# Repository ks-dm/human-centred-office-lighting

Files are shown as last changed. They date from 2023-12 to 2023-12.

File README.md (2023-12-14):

# human-centred-office-lighting
 
 This project pilots an ergonomic lighting system that mimics natural daylight, complementing the human environment, created for my 4th year Internet of Things elective module.

 This repository contains relevant code, tools and files to recereate the tests outline in the [report](doc/Human_centred_office_lighting.pdf), found under doc.
 
## Video
<a href="https://www.youtube.com/watch?v=UIQVlB2CDCI">
    
</a>

# CAD
Ive included relevant STEP files and parts lists in case you want to build the skylights and interface detailed in the [report](doc/Human_centred_office_lighting.pdf)

## Skylights
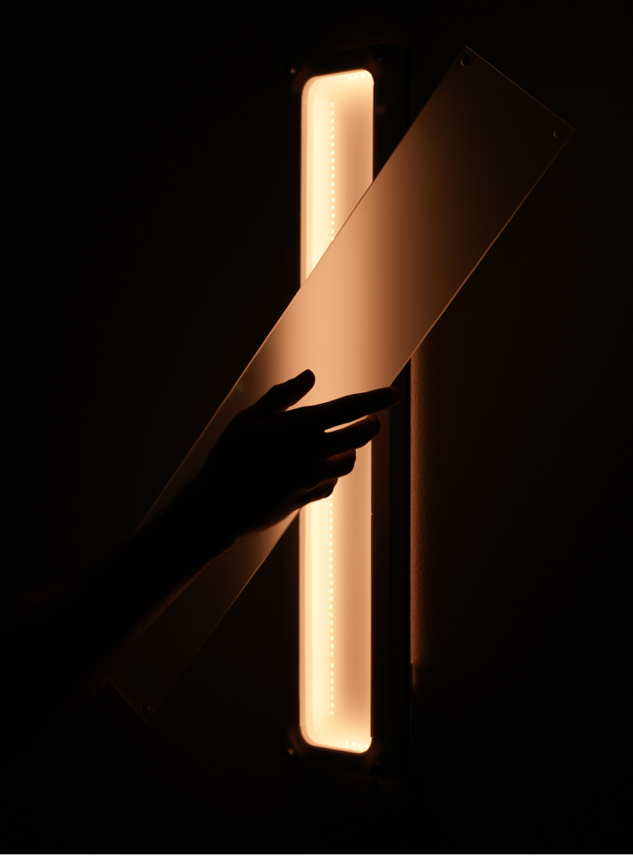
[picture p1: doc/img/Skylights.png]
Skylight


The skylights can be made using only a laser cutter, and I've included the .dxf files for each sheet material in this repo. Adjust the power and speed according to you machine specs.

The enclosures are made from the following materials:
 - [144/m WS2812B RGB LED strip](https://www.amazon.co.uk/dp/B07Q9KCC6M?psc=1&ref=ppx_yo2ov_dt_b_product_details), these are unrbanded neopixels, and I was able to fit around 174 of them in each Skylight. That equated to around 4 Metres to make 3 Skylights. You'll have to cut these into two long strips of 75 LEDs and two short strips of 12 LEDs per light, and solder them back into a continuous loop.
 - [9mm birch plywood](https://www.techsoft.co.uk/products/laser-cutting-materials/laser-grade-plywood-birch), The inner volume of the skylight is created with 3 layers of this 9mm laser ply, connected with wood glue. The DXF file included splits each layer into 4 parts for better tesselation and material use. You could also route this part out of a thicker stock of MDF or plywood if you have access to a CNC.
 - [3mm White Acrylic](https://www.techsoft.co.uk/products/laser-cutting-materials/acrylic-coloured-clear), this amkes up the tob and bottom of the plywood sandwhich. The LED strips also get attached to the top piece of acrylic. Refer to the video to see how this is done.
 - [3mm Frosted Perspex](https://www.cutmy.co.uk/plastic/acrylic-perspex-sheets/frosted/), I reccomend getting a large stock of this and lasercutting.
 - [12mm standoffs](https://www.amazon.co.uk/dp/B0851MNP1F?psc=1&ref=ppx_yo2ov_dt_b_product_details) Any generic standoff will work, but the brushed steel ones used for mirrors help create a nice touch!

## Ambient interface
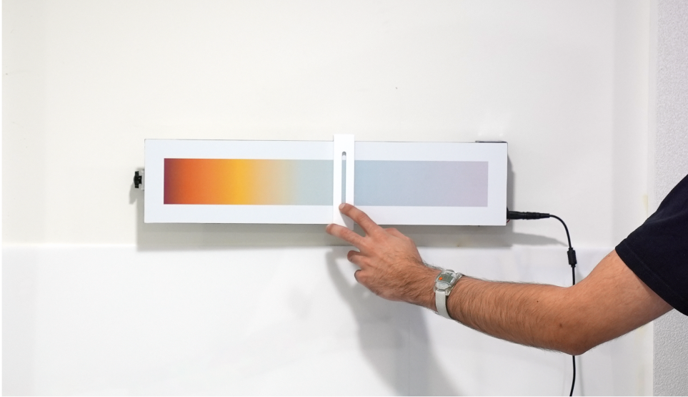
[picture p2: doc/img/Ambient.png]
Interface


The ambient interface uses a variety of readily available 3D printer parts, a custom dibond panel and a few 3D printed sections. I've linked below UK based distributors, but you should be able to find these parts locally pretty easily.

Components:
 - [2040 V-Slot Aluminium Profile](https://printermods.co.uk/products/sku11014?variant=39904045334678) cut to 450mm
 - [3D printer Belt Tensioner](https://printermods.co.uk/products/sku12534?variant=43025082056950) you can probably get away with 3D printing one of these and adding a GT2 20T timing belt pulley yourself
 - [M4 T-Nuts](https://printermods.co.uk/products/sku11148?variant=36960296272022) used to attach everything to the 2040 profile, including wall mounts
 - [Pulley wheels w/ bearing](https://printermods.co.uk/products/sku10855?variant=36915990429846) Attached these to the printed gantry with M5 nuts / bolts
 - [GT2-6mm Timing Belt](https://printermods.co.uk/products/sku12225?variant=39977974562966)
 - [TMC2130 Stepper motor driver](https://printermods.co.uk/products/sku10554?variant=37188251451542) Feel free to substitute - this operates nice and silently on 12-24V
 - [Endstop limit switch](https://printermods.co.uk/products/sku11838?variant=37518415102102) CAD is dimensioned to fit this PCB, however it seems to be a common form factor of this switch
 - [Raspberry Pi Zero](https://shop.pimoroni.com/products/raspberry-pi-zero-2-w?variant=39493046075475) You'll need a microSD card, keyboard, mouse, monitor and 5V Micro USB power supply to program this. Pimoroni offer a lot of these accesories -  really good UK based supplier
 - [BH1745 Luminance and Colour Sensor](https://shop.pimoroni.com/products/bh1745-luminance-and-colour-sensor-breakout?variant=12767599755347) I used the pimoroni breakout version of this sensor (not the adafruit one), so CAD reflects this.
 - [NEMA17 Stepper Motor](https://shop.pimoroni.com/products/nema-stepper-motor?variant=31384801017939)
 - [120mm * 523mm custom printed white aluminium dibond](https://www.vcprint.co.uk/dibond-aluminium-signs.html) I used this print shop for the project, just send them an email asking for a custom size and indlude the [GRADIENT.pdf](cad/GRADIENT.pdf) file
 - [Large Command strips](https://www.screwfix.com/p/command-self-adhesive-strips-assorted-16-piece-set/109hp) Great for mounting both the interface and skylights. Check your local hardware store, they will mjost likely stock these
 - [Universal power adapter](https://www.amazon.co.uk/gp/product/B09TRL3XV9/ref=ox_sc_act_title_1?smid=A3QFP7NSA4Z43O&psc=1) You'll need these to power the lights and interface. I reccomend this variety as theyre adjustable and include multiple adapters, including the terminal connector used in this project

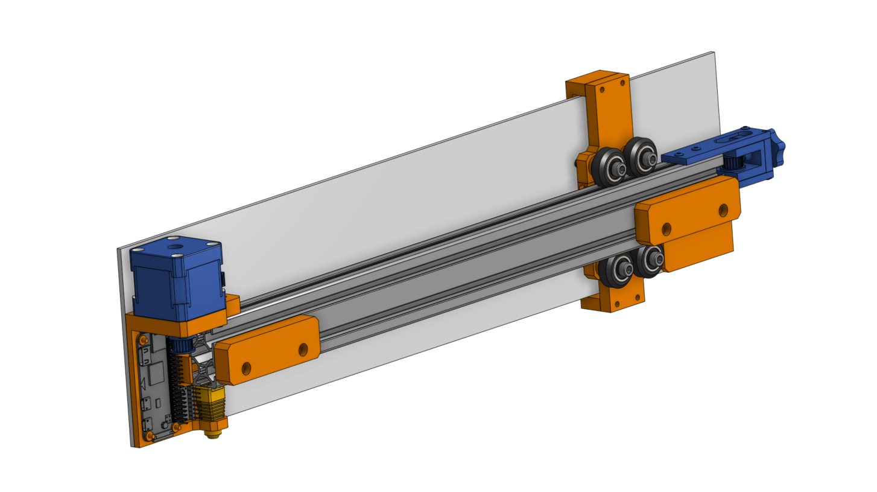
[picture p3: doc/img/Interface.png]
Printed elements in Orange

3D printed components:
 - [Wall_Mount.STL](cad/stl/Wall_Mount.stl), you'll need to of these. They attach to 2040 extrusion using T-Nuts, and then use command strips to stick to the wall
 - [Gantry_Front.STL](cad/stl/Gantry_Front.stl)
 - [Gantry_Back.STL](cad/stl/Gantry_Back.stl)
 - [Gantry_Clamp.STL](cad/stl/Gantry_Clamp.stl), this clamps the loose end of the timing belt to the gantry, and is secured to Gantry_back with two M3 bolts. I used threaded inserts but should work fine without
 - [Stepper_Mount.STL](cad/stl/Stepper_Mount.stl), houses the Pi, stepper, limit switch, motor driver and DC terminal connector. Attaches to the 2040 extrusion via T-Nuts. Stick to the bottom left of the Dibond back with expoxy or double sided-tape
 - [Other_Mount.STL](cad/stl/Other_Mount.stl), this sticks to the bottom right corner of the dibond, and secures the tensioner end of the 2040 extrusion. I reccomend sticking the Dibond to these mounts once everything else has been assembled onto the extrusion

You'll also need access to Jumper cables, M3, M4, M5 nuts and bolts as well as some general adhesive such as two part epoxy. Refer to the Step file to see how everything comes together, I've made sure everything is toleranced accurately so you can convert any part to STLs to print if you can't source them. 

# Prototyping

Prototyping

This project uses a wide variety of tools and methods to prototype the effects outlined in the report. For repeatability's sake, I've included as many as possible in this repository.

### Required Software:

1. [Download and install Processing 4](https://processing.org/download)
    - add the video library for processing 4 (navigate to sketch→ library manager)
2. [Download and install Arduino](https://www.arduino.cc/en/software)
    - Download and install the [Teensyduino](https://www.pjrc.com/teensy/td_download.html) Add-On for Arduino
    - add the Teensy Board Library (via the arduino board manager)
3. Get a Protopie Pro License with at least 1 Editor seat - if you're a student you can apply for a 1 year free trial
4. [Download and install Protopie Studio](https://www.protopie.io/download)
5. [Download and install Protopie Connect](https://www.protopie.io/download#connect-download)
6. [Download and install TouchDesigner](https://derivative.ca/download)

You can edit and test the individual protopie files in the main **protopie** application. However, if you want to run them in a connected mode, you have to load the local protopie files into the **protopie connect** application and launch them from there. Additionally, make sure all devices use the same WiFi.

## Screen Grabber
Essentially mirrors your screen onto your WS2812B (Neopixel) LED Strip. Really useful for prototyping lighting animations and effects before having to commit anything to code.

- [**ScreenPixels_OctoWS2811_Grabber.pde**](proto/ScreenPixels_OctoWS2811_Grabber.pde) --> a java based processing sketch that grabs pixel values from your screen and sends them as RGB values via USB to the teensy board, which drives the LED strip

- [**VideoDisplay_OctoWS2811.ino**](proto/VideoDisplay_OctoWS2811_Teensy4.ino) (this is the code that runs on the little Teensy board. It transforms the incoming RGB values from USB, and outputs them as LED signals via Pin 2.)

### Potential additional actions that might need to be taken:
- Update the serial port in "ScreenPixels_OctoWS2811_Grabber.pde", line 85
- Grant Desktop access for the Processing Sketch, so that the Java Robot can track your screen content and send the RGB values to the Teensy board via USB.

## TouchDesigner 
Free for non-commercial use, this node-based visual programming language is used throughout multimedia experience and interaction design. In this project, I connected a particle system to the OpenWeatherMap API, and used the Grabber tool to mirror the behavioir onto the skylights
- [Weather.toe](proto/Weather.toe) You have to reposition and resize the Weather.toe file window to match the monitored area of your screen.

# Main Python file

[Circadian.py](/firmware/Circadian-v1.py) Is configured to run on a Raspberry Pi Zero with the following pinout:

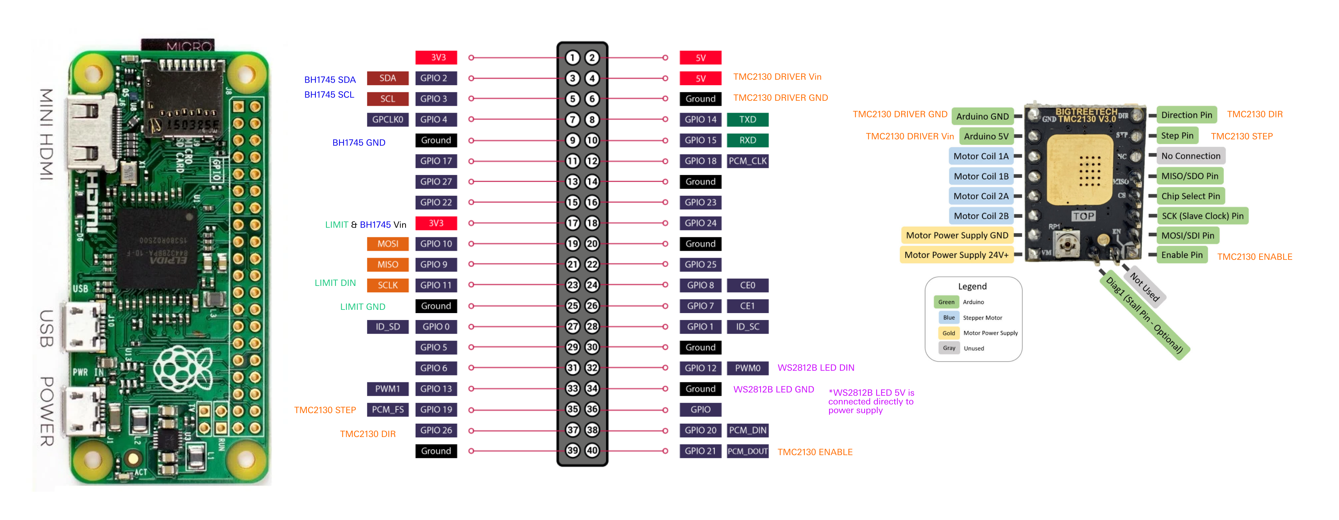
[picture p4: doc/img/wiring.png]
wiring


And uses the following libraries:
 - [Pysolar](https://pypi.org/project/pysolar/)
 - [Astral](https://pypi.org/project/astral/)
 - [Neopixel](https://pypi.org/project/neopixel/)
 - [Ephem](https://pypi.org/project/ephem/)
 - [Colour science](https://pypi.org/project/colour-science/)
 - [BH1745](https://github.com/pimoroni/bh1745-python)

You'll have to 'sudo pip install library_name' each of these on your Pi. 
[Thingspeak Channel](https://thingspeak.com/channels/2366620)

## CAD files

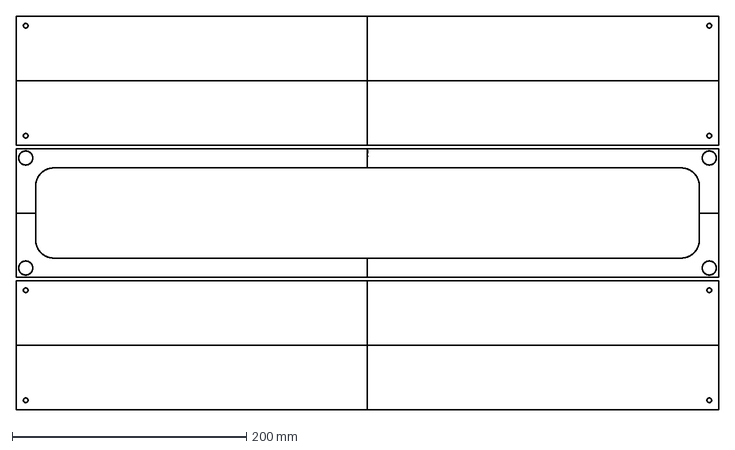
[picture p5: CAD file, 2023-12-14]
cad/dxf/Acrylic_Top.dxf
600.0 x 336.0 mm

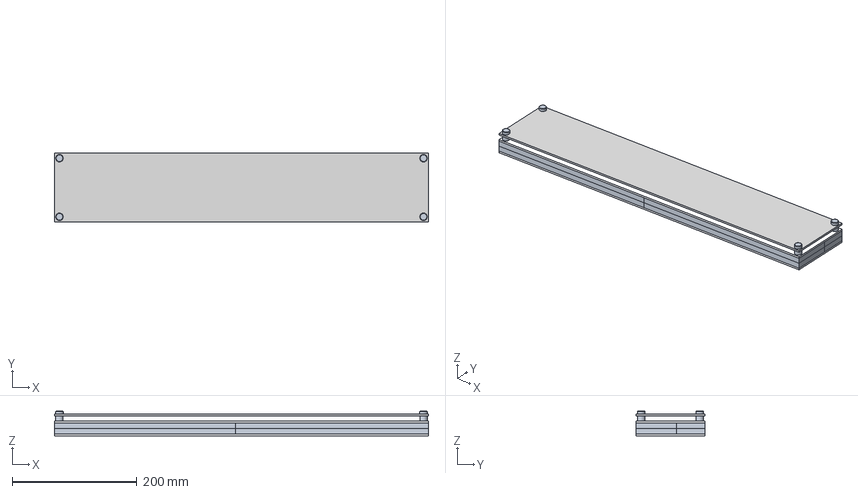
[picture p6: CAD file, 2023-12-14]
cad/SKYLIGHT.step
600.0 x 110.0 x 40.0 mm

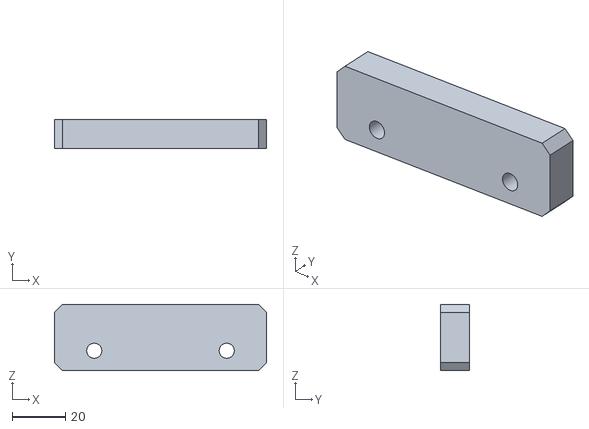
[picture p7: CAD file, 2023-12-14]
cad/stl/Wall_Mount.stl
80.0 x 11.0 x 25.0

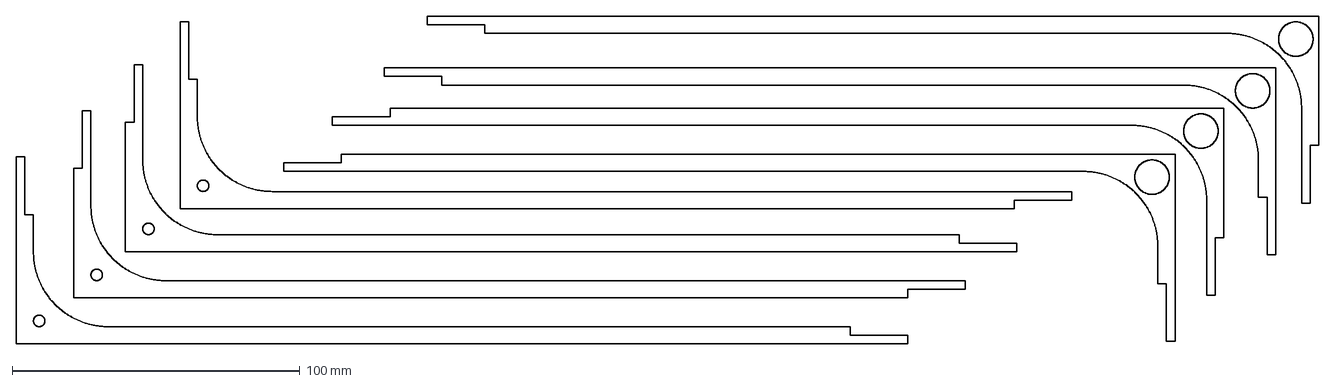
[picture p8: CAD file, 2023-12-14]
cad/dxf/Plywood.dxf
453.0 x 114.0 mm

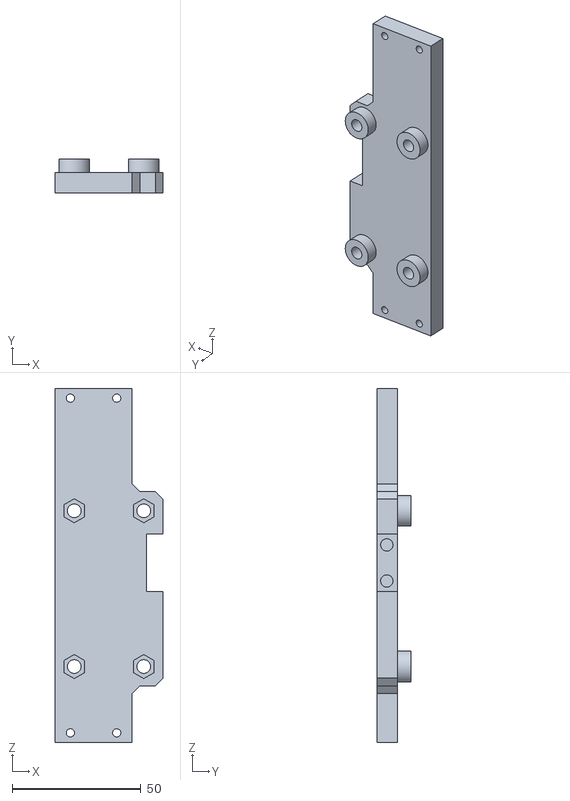
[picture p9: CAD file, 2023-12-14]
cad/stl/Gantry_Back.stl
42.0 x 13.3 x 137.5

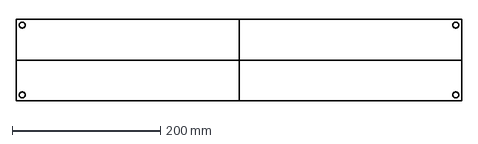
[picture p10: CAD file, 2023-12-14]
cad/dxf/Perspex.dxf
600.0 x 110.0 mm

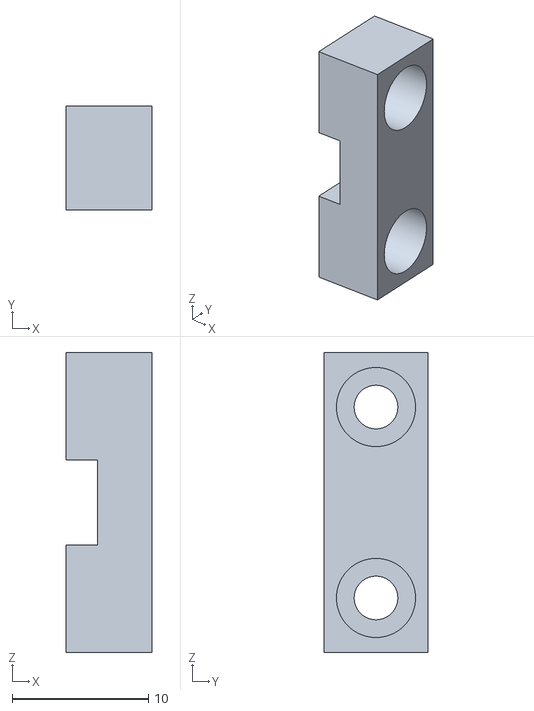
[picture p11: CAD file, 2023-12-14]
cad/stl/Gantry_Clamp.stl
6.30 x 7.65 x 22.0

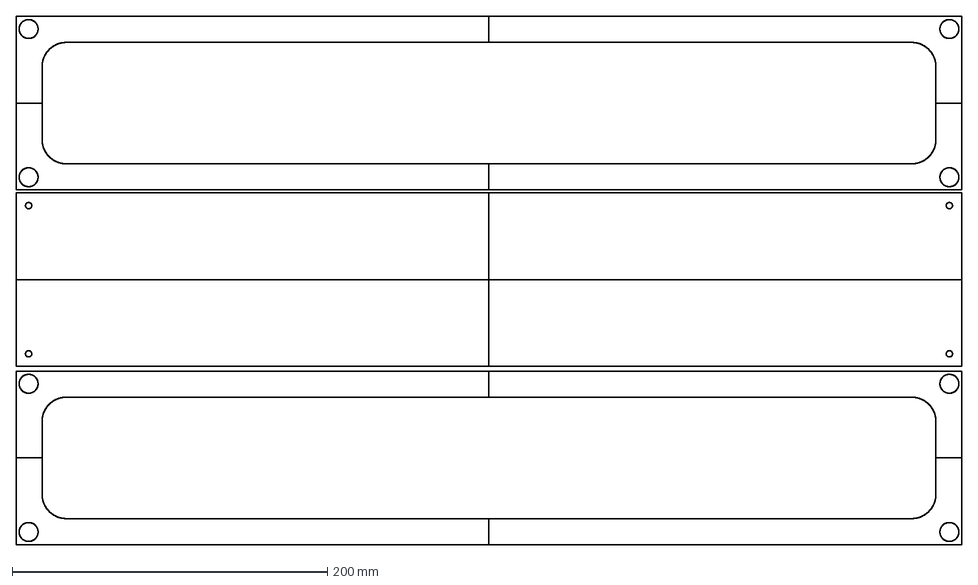
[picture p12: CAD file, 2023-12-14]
cad/dxf/Acrylic_Bottom.dxf
600.0 x 335.0 mm

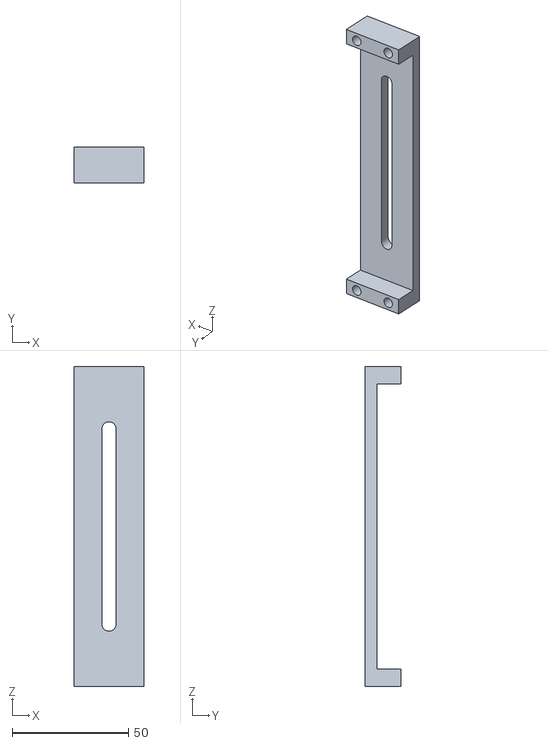
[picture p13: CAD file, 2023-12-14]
cad/stl/Gantry_Front.stl
30.0 x 15.3 x 137.5

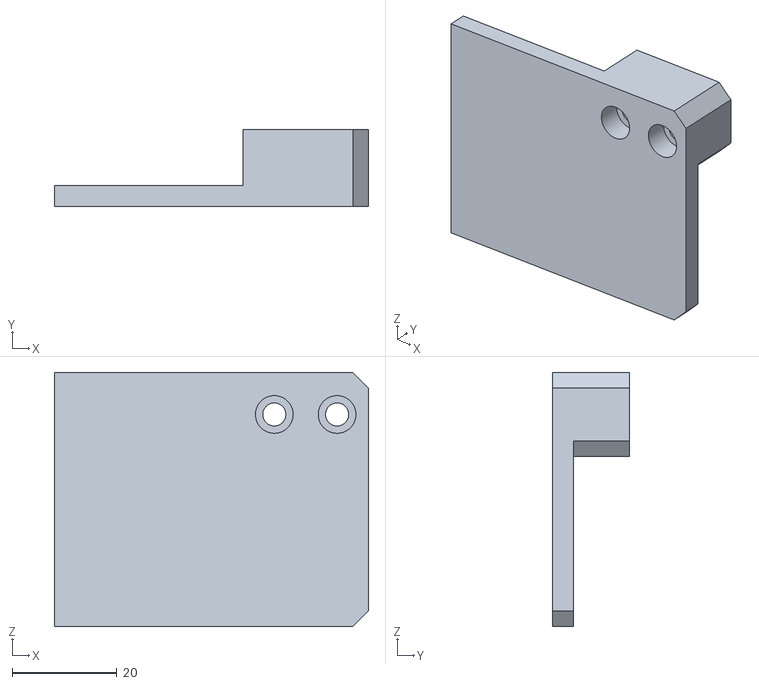
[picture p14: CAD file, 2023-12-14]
cad/stl/Other_Mount.stl
60.0 x 14.7 x 48.6

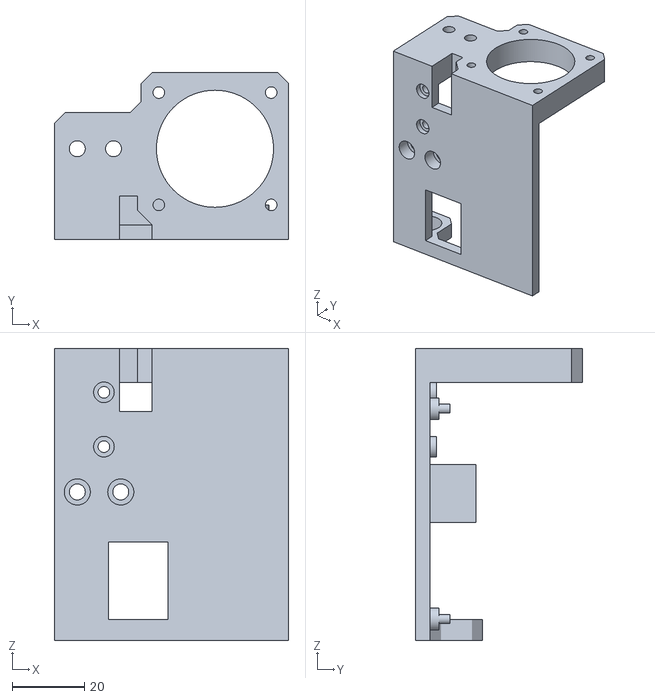
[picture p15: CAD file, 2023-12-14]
cad/stl/Stepper_Mount.stl
64.7 x 46.0 x 80.6

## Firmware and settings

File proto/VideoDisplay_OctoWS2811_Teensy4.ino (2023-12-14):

/*  OctoWS2811 VideoDisplay.ino - Video on LEDs, from a PC, Mac, Raspberry Pi
    http://www.pjrc.com/teensy/td_libs_OctoWS2811.html
    Copyright (c) 2020 Paul Stoffregen, PJRC.COM, LLC

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
Update: The movie2serial program which transmit data has moved to "extras"
https://github.com/PaulStoffregen/OctoWS2811/tree/master/extras
 
  Required Connections
  --------------------
    pin 2:  LED Strip #1    OctoWS2811 drives 8 LED Strips.
    pin 14: LED strip #2    All 8 are the same length.
    pin 7:  LED strip #3
    pin 8:  LED strip #4    A 100 to 220 ohm resistor should used
    pin 6:  LED strip #5    between each Teensy pin and the
    pin 20: LED strip #6    wire to the LED strip, to minimize
    pin 21: LED strip #7    high frequency ringining & noise.
    pin 5:  LED strip #8
    pin 15 & 16 - Connect together, but do not use
    pin 4:  Do not use
    pin 3:  Do not use as PWM.  Normal use is ok.
    pin 12: Frame Sync

    When using more than 1 Teensy to display a video image, connect
    the Frame Sync signal between every board.  All boards will
    synchronize their WS2811 update using this signal.

    Beware of image distortion from long LED strip lengths.  During
    the WS2811 update, the LEDs update in sequence, not all at the
    same instant!  The first pixel updates after 30 microseconds,
    the second pixel after 60 us, and so on.  A strip of 120 LEDs
    updates in 3.6 ms, which is 10.8% of a 30 Hz video frame time.
    Doubling the strip length to 240 LEDs increases the lag to 21.6%
    of a video frame.  For best results, use shorter length strips.
    Multiple boards linked by the frame sync signal provides superior
    video timing accuracy.

    A Multi-TT USB hub should be used if 2 or more Teensy boards
    are connected.  The Multi-TT feature allows proper USB bandwidth
    allocation.  Single-TT hubs, or direct connection to multiple
    ports on the same motherboard, may give poor performance.
*/

#include <OctoWS2811.h>

// The actual arrangement of the LEDs connected to this Teensy 3.0 board.
// LED_HEIGHT *must* be a multiple of 8.  When 16, 24, 32 are used, each
// strip spans 2, 3, 4 rows.  LED_LAYOUT indicates the direction the strips
// are arranged.  If 0, each strip begins on the left for its first row,
// then goes right to left for its second row, then left to right,
// zig-zagging for each successive row.
#define LED_WIDTH      87   // number of LEDs horizontally
#define LED_HEIGHT     48   // number of LEDs vertically (must be multiple of 8)
#define LED_LAYOUT     0    // 0 = even rows left->right, 1 = even rows right->left

// The portion of the video image to show on this set of LEDs.  All 4 numbers
// are percentages, from 0 to 100.  For a large LED installation with many
// Teensy 3.0 boards driving groups of LEDs, these parameters allow you to
// program each Teensy to tell the video application which portion of the
// video it displays.  By reading these numbers, the video application can
// automatically configure itself, regardless of which serial port COM number
// or device names are assigned to each Teensy 3.0 by your operating system.
#define VIDEO_XOFFSET  0
#define VIDEO_YOFFSET  0       // display entire image
#define VIDEO_WIDTH    100
#define VIDEO_HEIGHT   100

//#define VIDEO_XOFFSET  0
//#define VIDEO_YOFFSET  0     // display upper half
//#define VIDEO_WIDTH    100
//#define VIDEO_HEIGHT   50

//#define VIDEO_XOFFSET  0
//#define VIDEO_YOFFSET  50    // display lower half
//#define VIDEO_WIDTH    100
//#define VIDEO_HEIGHT   50


const int ledsPerStrip = LED_WIDTH * LED_HEIGHT / 8;

DMAMEM int displayMemory[ledsPerStrip*6];
int drawingMemory[ledsPerStrip*6];
int incomingMemory[ledsPerStrip*6];
elapsedMicros elapsedUsecSinceLastFrameSync = 0;

const int config = WS2811_800kHz; // color config is on the PC side

OctoWS2811 leds(ledsPerStrip, displayMemory, drawingMemory, config);

void setup() {
  pinMode(12, INPUT_PULLUP); // Frame Sync
  Serial.setTimeout(50);
  leds.begin();
  leds.show();
}

void loop() {
//
// wait for a Start-Of-Message character:
//
//   '*' = Frame of image data, with frame sync pulse to be sent
//         a specified number of microseconds after reception of
//         the first byte (typically at 75% of the frame time, to
//         allow other boards to fully receive their data).
//         Normally '*' is used when the sender controls the pace
//         of playback by transmitting each frame as it should
//         appear.
//   
//   '$' = Frame of image data, with frame sync pulse to be sent
//         a specified number of microseconds after the previous
//         frame sync.  Normally this is used when the sender
//         transmits each frame as quickly as possible, and we
//         control the pacing of video playback by updating the
//         LEDs based on time elapsed from the previous frame.
//
//   '%' = Frame of image data, to be displayed with a frame sync
//         pulse is received from another board.  In a multi-board
//         system, the sender would normally transmit one '*' or '$'
//         message and '%' messages to all other boards, so every
//         Teensy 3.0 updates at the exact same moment.
//
//   '@' = Reset the elapsed time, used for '$' messages.  This
//         should be sent before the first '$' message, so many
//         frames are not played quickly if time as elapsed since
//         startup or prior video playing.
//   
//   '?' = Query LED and Video parameters.  Teensy 3.0 responds
//         with a comma delimited list of information.
//
  int startChar = Serial.read();

  if (startChar == '*') {
    // receive a "master" frame - we send the frame sync to other boards
    // the sender is controlling the video pace.  The 16 bit number is
    // how far into this frame to send the sync to other boards.
    unsigned int startAt = micros();
    unsigned int usecUntilFrameSync = 0;
    int count = Serial.readBytes((char *)&usecUntilFrameSync, 2);
    if (count != 2) return;
    count = Serial.readBytes((char *)incomingMemory, sizeof(incomingMemory));
    if (count == sizeof(incomingMemory)) {
      copyIncomingToDrawing();
      unsigned int endAt = micros();
      unsigned int usToWaitBeforeSyncOutput = 100;
      if (endAt - startAt < usecUntilFrameSync) {
        usToWaitBeforeSyncOutput = usecUntilFrameSync - (endAt - startAt);
      }
      digitalWrite(12, HIGH);
      pinMode(12, OUTPUT);
      delayMicroseconds(usToWaitBeforeSyncOutput);
      digitalWrite(12, LOW);
      // WS2811 update begins immediately after falling edge of frame sync
      digitalWrite(13, HIGH);
      leds.show();
      digitalWrite(13, LOW);
    }

  } else if (startChar == '$') {
    // receive a "master" frame - we send the frame sync to other boards
    // we are controlling the video pace.  The 16 bit number is how long
    // after the prior frame sync to wait until showing this frame
    unsigned int usecUntilFrameSync = 0;
    int count = Serial.readBytes((char *)&usecUntilFrameSync, 2);
    if (count != 2) return;
    count = Serial.readBytes((char *)incomingMemory, sizeof(incomingMemory));
    if (count == sizeof(incomingMemory)) {
      copyIncomingToDrawing();
      digitalWrite(12, HIGH);
      pinMode(12, OUTPUT);
      while (elapsedUsecSinceLastFrameSync < usecUntilFrameSync) /* wait */ ;
      elapsedUsecSinceLastFrameSync -= usecUntilFrameSync;
      digitalWrite(12, LOW);
      // WS2811 update begins immediately after falling edge of frame sync
      digitalWrite(13, HIGH);
      leds.show();
      digitalWrite(13, LOW);
    }

  } else if (startChar == '%') {
    // receive a "slave" frame - wait to show it until the frame sync arrives
    pinMode(12, INPUT_PULLUP);
    unsigned int unusedField = 0;
    int count = Serial.readBytes((char *)&unusedField, 2);
    if (count != 2) return;
    count = Serial.readBytes((char *)incomingMemory, sizeof(incomingMemory));
    if (count == sizeof(incomingMemory)) {
      copyIncomingToDrawing();
      elapsedMillis wait = 0;
      while (digitalRead(12) != HIGH && wait < 30) ; // wait for sync high
      while (digitalRead(12) != LOW && wait < 30) ;  // wait for sync high->low
      // WS2811 update begins immediately after falling edge of frame sync
      if (wait < 30) {
        digitalWrite(13, HIGH);
        leds.show();
        digitalWrite(13, LOW);
      }
    }

  } else if (startChar == '@') {
    // reset the elapsed frame time, for startup of '$' message playing
    elapsedUsecSinceLastFrameSync = 0;

  } else if (startChar == '?') {
    // when the video application asks, give it all our info
    // for easy and automatic configuration
    Serial.print(LED_WIDTH);
    Serial.write(',');
    Serial.print(LED_HEIGHT);
    Serial.write(',');
    Serial.print(LED_LAYOUT);
    Serial.write(',');
    Serial.print(0);
    Serial.write(',');
    Serial.print(0);
    Serial.write(',');
    Serial.print(VIDEO_XOFFSET);
    Serial.write(',');
    Serial.print(VIDEO_YOFFSET);
    Serial.write(',');
    Serial.print(VIDEO_WIDTH);
    Serial.write(',');
    Serial.print(VIDEO_HEIGHT);
    Serial.write(',');
    Serial.print(0);
    Serial.write(',');
    Serial.print(0);
    Serial.write(',');
    Serial.print(0);
    Serial.println();

  } else if (startChar >= 0) {
    // discard unknown characters
  }
}


// The PC transmits data in the transposed format Teensy 3.x uses.
// This copy function undoes the transpose, so the pixels are
// put back into the simpler framebuffer format Teensy 4.x uses.
void copyIncomingToDrawing() {
  const uint32_t width = (LED_WIDTH * LED_HEIGHT / 8) * 3;
  const uint8_t *src = (const uint8_t *)incomingMemory;
  uint8_t *dest = (uint8_t *)drawingMemory;

  for (uint32_t x=0; x < width; x++) {
    uint8_t b[8] = {0, 0, 0, 0, 0, 0, 0, 0};
    for (uint8_t mask = 0x80; mask; mask >>= 1) {
      uint8_t bits = *src++;
      if (bits & 0x01) b[0] |= mask;
      if (bits & 0x02) b[1] |= mask;
      if (bits & 0x04) b[2] |= mask;
      if (bits & 0x08) b[3] |= mask;
      if (bits & 0x10) b[4] |= mask;
      if (bits & 0x20) b[5] |= mask;
      if (bits & 0x40) b[6] |= mask;
      if (bits & 0x80) b[7] |= mask;
    }
    dest[width*0] = b[0];
    dest[width*1] = b[1];
    dest[width*2] = b[2];
    dest[width*3] = b[3];
    dest[width*4] = b[4];
    dest[width*5] = b[5];
    dest[width*6] = b[6];
    dest[width*7] = b[7];
    dest = dest + 1;
  }
}

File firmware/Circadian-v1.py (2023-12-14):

import time
import numpy as np
from astral.sun import sun
from astral import LocationInfo
from pysolar.solar import*
from datetime import datetime
import datetime
import board
import neopixel
import math
from bh1745 import BH1745
import colour
import urllib.request
import requests
import threading
import ephem

#Set maximum and minimum temperature ranges
TEMP_DAY = 7000
TEMP_NIGHT = 1000 

#WS2812 LED configuration
pixel_pin = board.D18
num_pixels = 6
ORDER=neopixel.GRB
pixels = neopixel.NeoPixel(pixel_pin, num_pixels, brightness=0.2, auto_write=False, pixel_order=ORDER)

#Sensor setup
bh1745 = BH1745()
bh1745.setup
bh1745.set_leds(0)

#Get current solar elevation and solar noon, dawn and dusk based on Latitude and Longitude
def get_elevation():
    date = datetime.datetime.now()
    LAT = 51.478710
    LON = -0.201702
    location = LocationInfo("Home", "England", "GMT",LAT,LON)
    
    sun_times = sun(location.observer, date = date)
    
    dawn =sun_times["dawn"]
    dusk =sun_times["dusk"]
    noon =sun_times["noon"]
    dawn_elevation=get_altitude(LAT,LON,dawn)
    dusk_elevation=get_altitude(LAT,LON,dusk)
    noon_elevation=get_altitude(LAT,LON,noon)
    solar_dawn =dawn.strftime('%H:%M:%S')
    solar_dusk =dusk.strftime('%H:%M:%S')
    solar_noon =noon.strftime('%H:%M:%S')
    #print(dawn_elevation)
    
    now = datetime.datetime.now(datetime.timezone.utc)
    current_elevation = get_altitude(LAT,LON,now) 
    return current_elevation, dusk_elevation, noon_elevation, solar_dawn, solar_dusk, solar_noon

#Get current temperature value (kelvin) from solar elevation by normalising 
def elevation_to_col_temp(current_elevation, TEMP_DAY, TEMP_NIGHT, ELEV_MAX, ELEV_MIN):
    if current_elevation <= ELEV_MIN:
        return TEMP_NIGHT
    else:
        colour_temperature = TEMP_NIGHT + (TEMP_DAY - TEMP_NIGHT)*((current_elevation - ELEV_MIN)/(ELEV_MAX - ELEV_MIN))
        return colour_temperature

#Returns precise solar time for comparisions
def solartime(sun=ephem.Sun()):
    observer = ephem.Observer()
    observer.date = datetime.datetime.now(datetime.timezone.utc)
    observer.long = '0:7:5.01312'
    sun.compute(observer)
    hour_angle = observer.sidereal_time() - sun.ra
    return ephem.hours(hour_angle + ephem.hours('12:00')).norm


#Returns weather condition ID
def weathercheck():
    api_key='4f1d4d28d7c8f2ad4e687551a05b4bc6'
    city='London'
    url= f'http://api.openweathermap.org/data/2.5/weather?q={city}&appid={api_key}'
    response=requests.get(url)
    if response.status_code == 200:
        data=response.json()
        temp = data['main']['temp']
        desc=data['weather'][0]['id']
        return desc
    else:
        print('Error fetching data')
    
#Custom algorithm to convert from colour temperture to RGB based on Charity's raw blackbody data file. Also tells LEDs to display said RGB colour when called
def convert_K_to_RGB(colour_temperature):
    #range check
    if colour_temperature < 1000: 
        colour_temperature = 1000
    elif colour_temperature > 40000:
        colour_temperature = 40000
    
    tmp_internal = colour_temperature / 100.0
    
    # red 
    if tmp_internal <= 66:
        red = 255
    else:
        tmp_red = 329.698727446 * math.pow(tmp_internal - 60, -0.1332047592)
        if tmp_red < 0:
            red = 0
        elif tmp_red > 255:
            red = 255
        else:
            red = tmp_red
    
    # green
    if tmp_internal <=66:
        tmp_green = 99.4708025861 * math.log(tmp_internal) - 161.1195681661
        if tmp_green < 0:
            green = 0
        elif tmp_green > 255:
            green = 255
        else:
            green = tmp_green
    else:
        tmp_green = 288.1221695283 * math.pow(tmp_internal - 60, -0.0755148492)
        if tmp_green < 0:
            green = 0
        elif tmp_green > 255:
            green = 255
        else:
            green = tmp_green
    
    # blue
    if tmp_internal >=66:
        blue = 255
    elif tmp_internal <= 19:
        blue = 0
    else:
        tmp_blue = 138.5177312231 * math.log(tmp_internal - 10) - 305.0447927307
        if tmp_blue < 0:
            blue = 0
        elif tmp_blue > 255:
            blue = 255
        else:
            blue = tmp_blue
    
    pixels.fill([int(red), int(green), int(blue)])
    pixels.show()
    print([red, green, blue])

#Reads current room colour temperature from BH1745 colour & luminance sensor. Uses colour science library for conversion
def measure():
    bh1745.set_measurement_time_ms(160)
    r, g, b= bh1745.get_rgb_scaled()
    if r > 0 or g > 0 or b > 0:
        RGB=np.array([r,g,b])
        XYZ=colour.sRGB_to_XYZ(RGB/255)
        xy=colour.XYZ_to_xy(XYZ)
        CCT=colour.xy_to_CCT(xy)
        if CCT < 0:
            return 0
        else:
            print(CCT)
            return CCT
    else:
        return 0

#Logs Measured colour temperature, target colour temperature, solar elevation, solar time and weather condition to thingspeak
def send_to_thingspeak(CCT, colour_temperature, current_elevation, solar_time, weather):
    HEADER='&field1={}&field2={}&field3={}&field4={}&field5={}'.format(CCT, colour_temperature, current_elevation, solar_time, weather)
    URL='https://api.thingspeak.com/update?api_key=HTHGPTK5QI3OY4SG'+HEADER
    data=urllib.request.urlopen(URL)

#main loop
while True:
    now = datetime.datetime.now(datetime.timezone.utc)
    current_elevation, ELEV_MIN, ELEV_MAX, solar_dawn, solar_dusk, solar_noon = get_elevation()
    CCT=measure()
    solar_time = solartime()
    weather = weathercheck()
    temperature = elevation_to_col_temp(current_elevation, TEMP_DAY, TEMP_NIGHT, ELEV_MAX, ELEV_MIN)
    convert_K_to_RGB(int(temperature))
    send_to_thingspeak(CCT, temperature, current_elevation, solar_time, weather)
    time.sleep(60)
